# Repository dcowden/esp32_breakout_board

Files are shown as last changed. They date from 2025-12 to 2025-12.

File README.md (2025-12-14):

# esp32 breakout boards

These are for  this board:

https://docs.espressif.com/projects/esp-dev-kits/en/latest/esp32/_images/esp32_devkitC_v4_pinlayout.png

## Included boards
 1. **esp32_breakout_smt**  A board designed to expose the stuff i need for xcc tracker, all on one board, with smt style mounts
 2. **esp32_breakout_tht** Through hole version of the above ( again designed for the xc case in mind
 3. **esp32_breakout_tht2** A simple board designed to just break out pins-- and then extned through a shield approach
 4. **esp32_breakout_tht2_shield** A shield for the agove that adds the stuff needed for xc application
 
## The stuff that the XC board needs

The xc board logs data from an nrf52840 and sends it to an esp32 , which processes further. 
The board needs:
   1. esp32 devkit c ( we need all the pins) (38 pin)
   2. seed xiao nrf52840  (14 pin) 
   3. ds3231 (isc) (weird 5 pin thing)
   4. i2c oled 
   5. micro sd card holder ( spi )

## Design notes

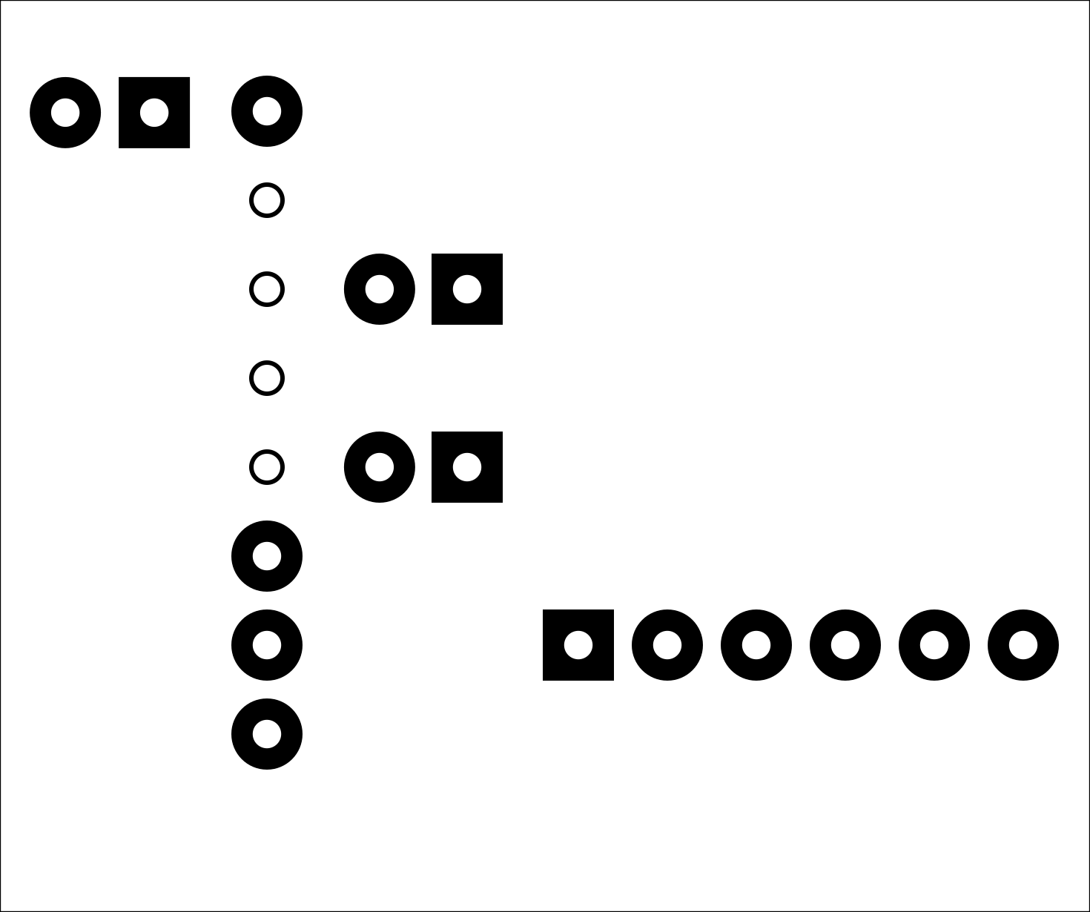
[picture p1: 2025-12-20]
sdcard_shield/board_art/mask-front.png

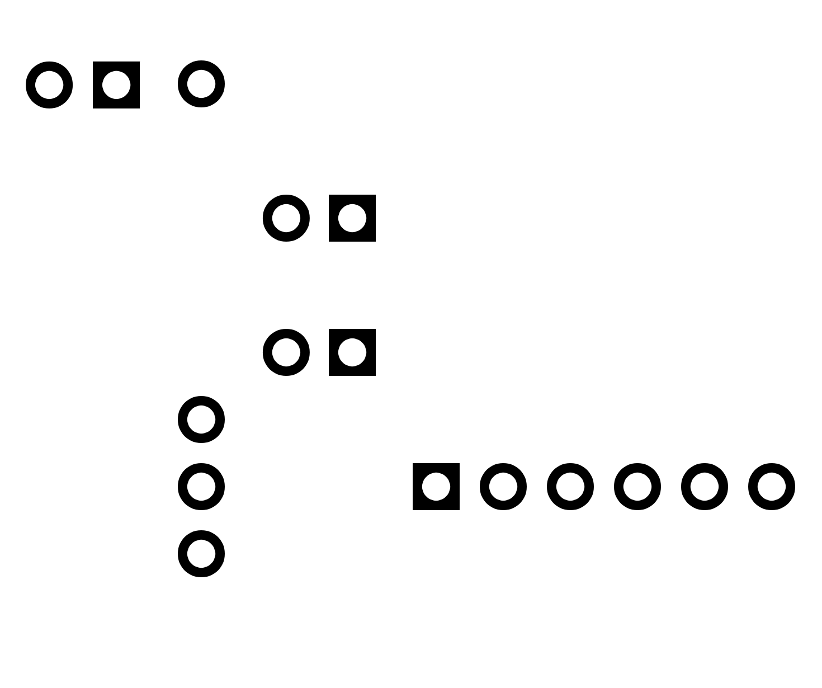
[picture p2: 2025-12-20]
sdcard_shield/board_art/mask-front_kerf.png

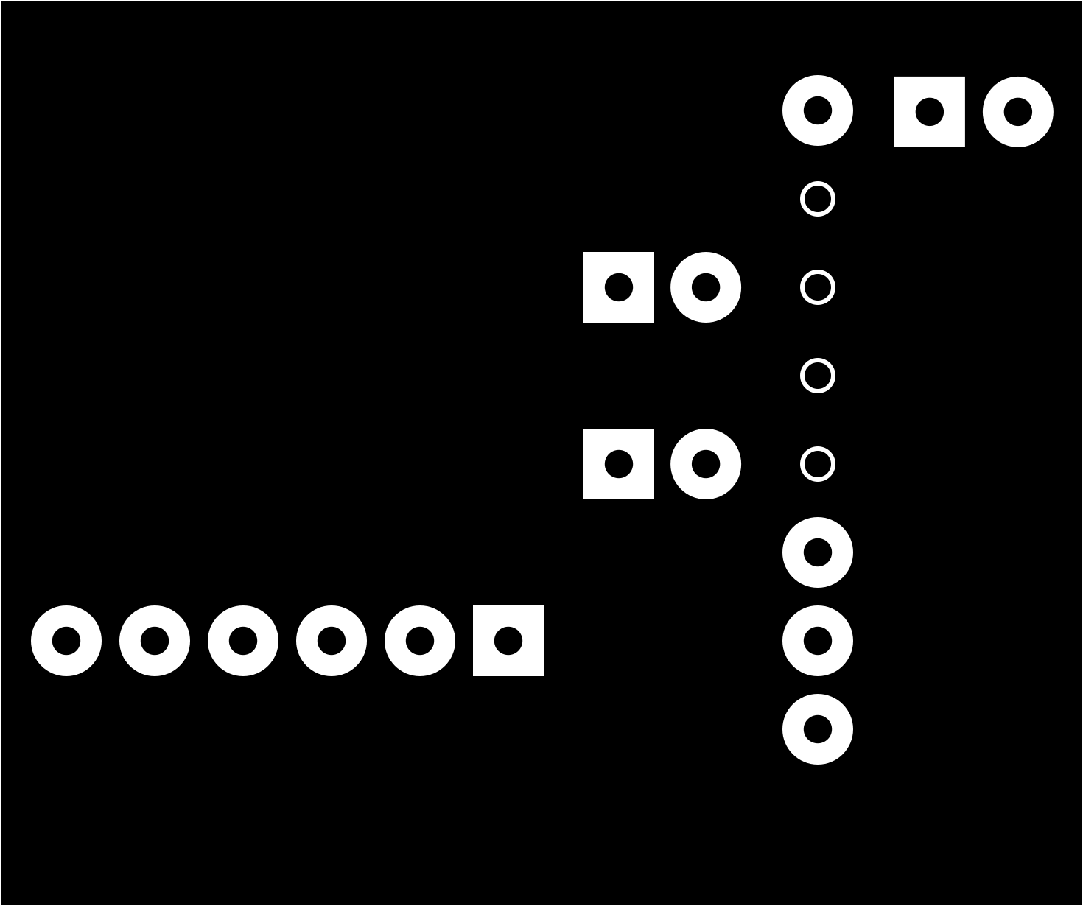
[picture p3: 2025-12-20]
sdcard_shield/board_art/back.png

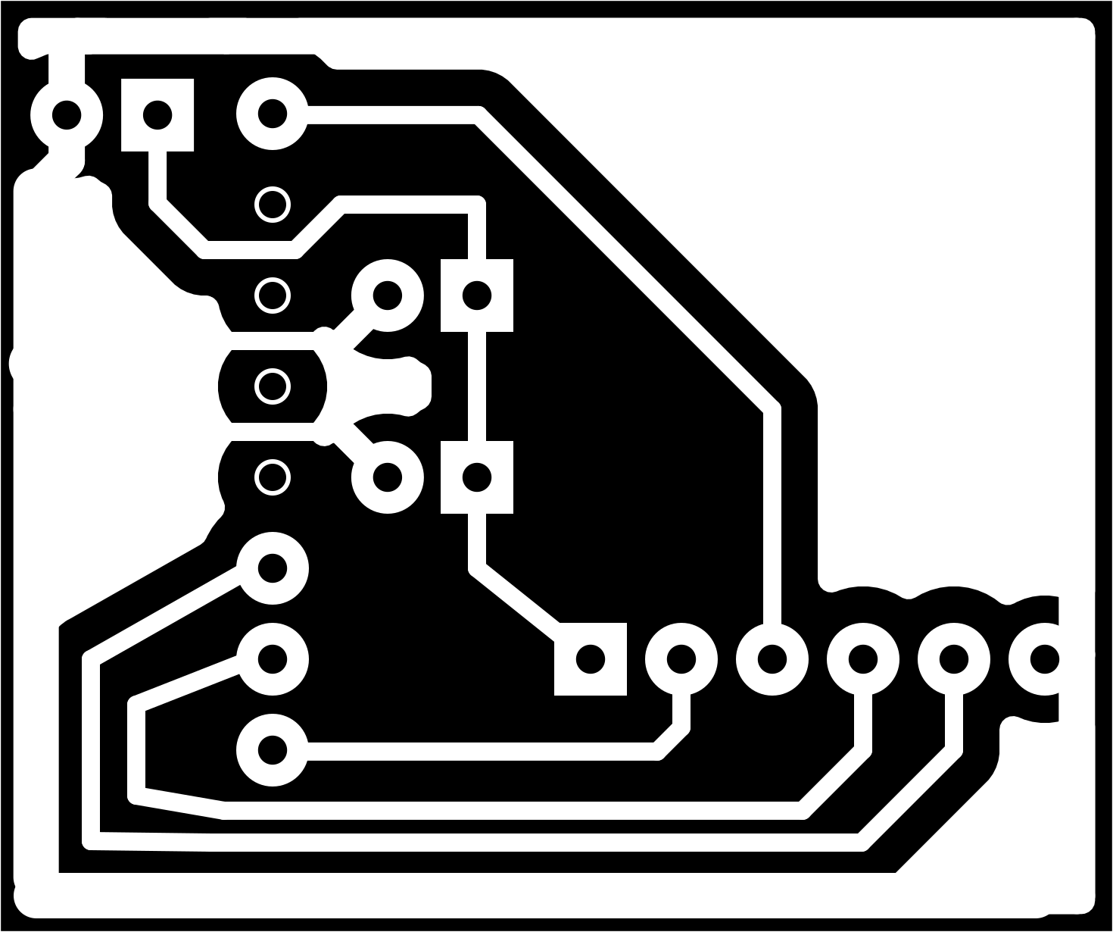
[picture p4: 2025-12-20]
sdcard_shield/board_art/front.png

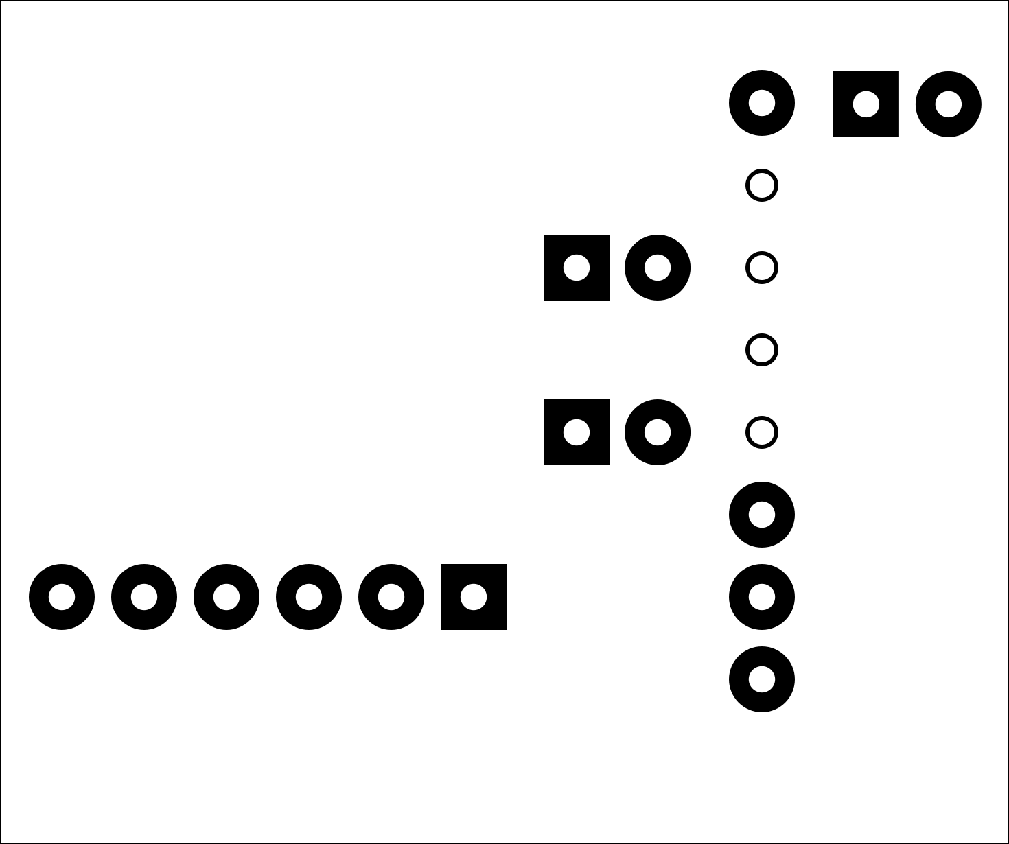
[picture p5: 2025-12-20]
sdcard_shield/board_art/mask-back.png

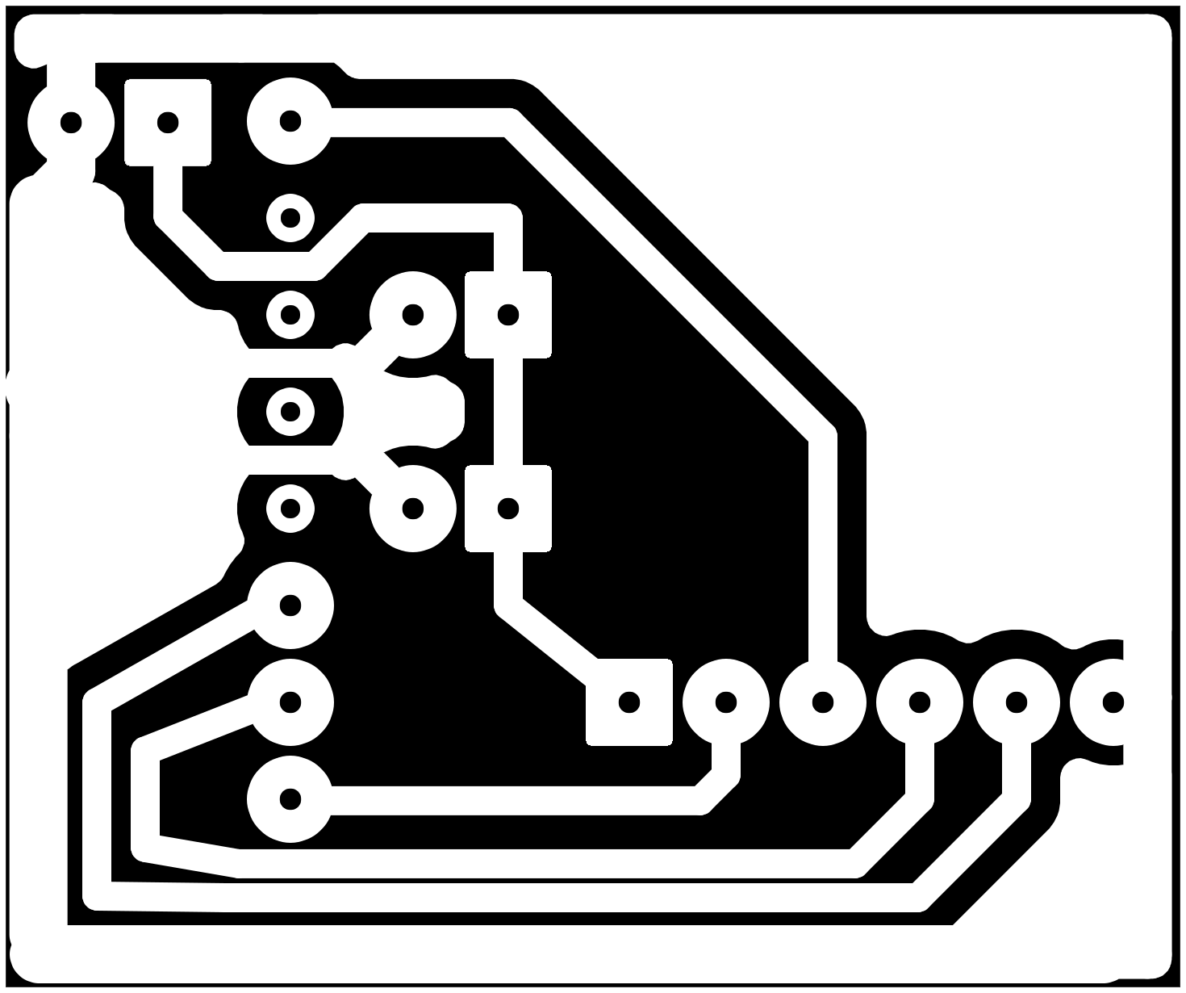
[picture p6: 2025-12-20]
sdcard_shield/board_art/front_kerf.png

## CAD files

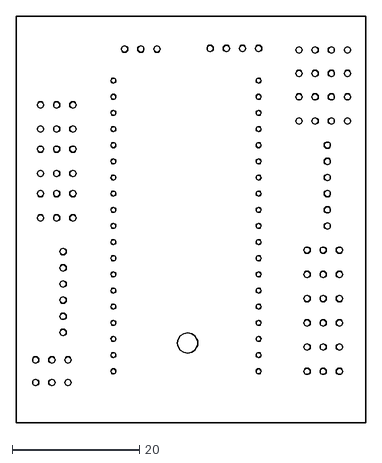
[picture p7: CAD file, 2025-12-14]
esp32_breakout_tht/board_art/back-silkscreen.dxf/esp32_breakout-Edge_Cuts.dxf
54.9 x 64.0

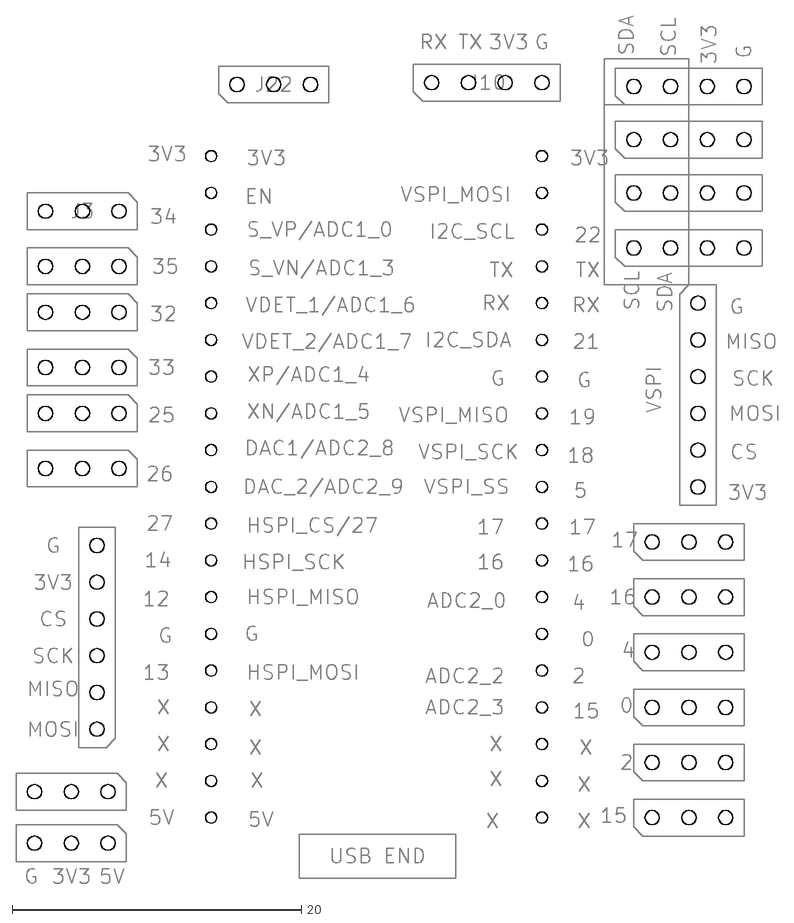
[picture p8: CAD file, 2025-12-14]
esp32_breakout_tht/board_art/front-silkscreen.dxf/esp32_breakout-F_Fab.dxf
52.6 x 59.9

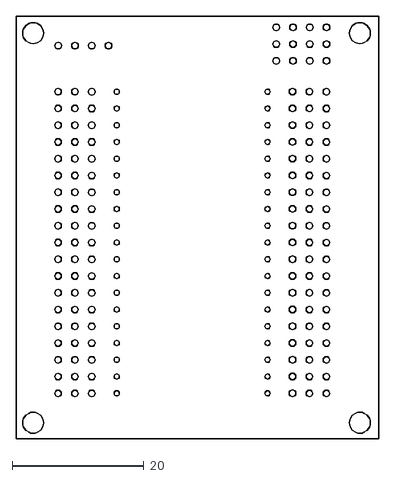
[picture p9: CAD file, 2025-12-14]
esp32_breakout_tht2/board_art/back-silkscreen.dxf/esp32_breakout-Edge_Cuts.dxf
54.9 x 64.0

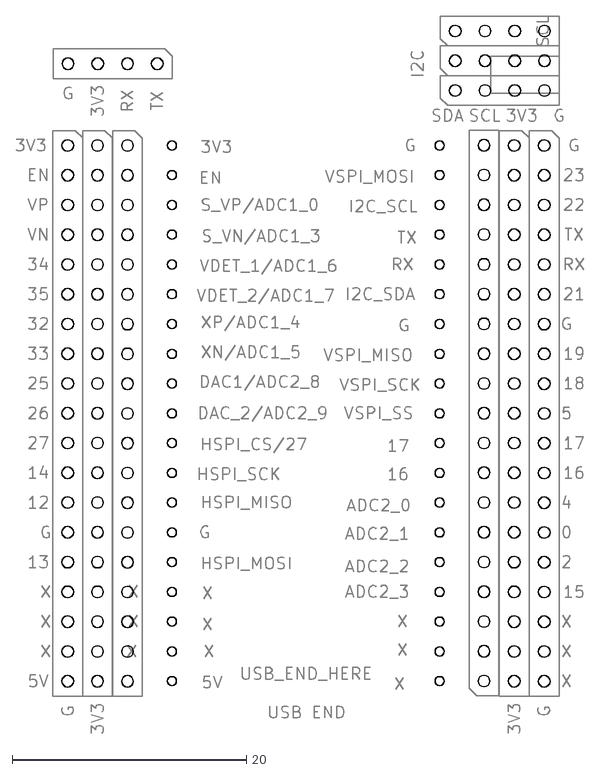
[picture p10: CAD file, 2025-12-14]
esp32_breakout_tht2/board_art/front-silkscreen.dxf/esp32_breakout-F_Fab.dxf
48.4 x 61.2

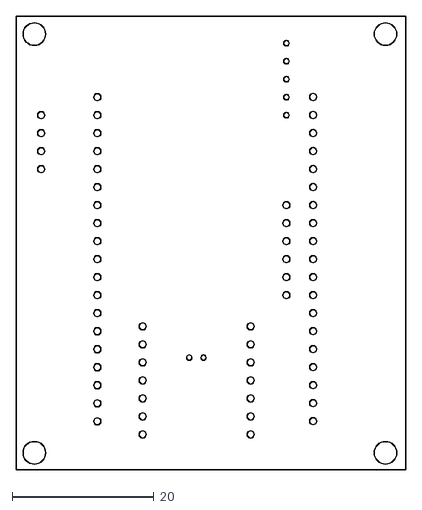
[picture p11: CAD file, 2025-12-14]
esp32_breakout_tht2_shield/board_art/back-silkscreen.dxf/esp32_breakout_shield-Edge_Cuts.dxf
54.9 x 64.0

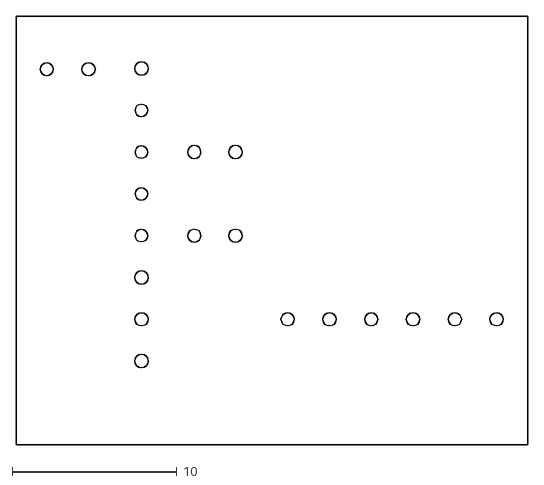
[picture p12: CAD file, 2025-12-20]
sdcard_shield/board_art/back-silkscreen.dxf/sdcard_shield-Edge_Cuts.dxf
31.1 x 26.0

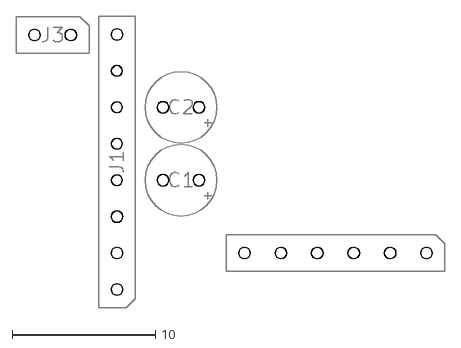
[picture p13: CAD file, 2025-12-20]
sdcard_shield/board_art/front-silkscreen.dxf/sdcard_shield-F_Fab.dxf
29.9 x 20.3

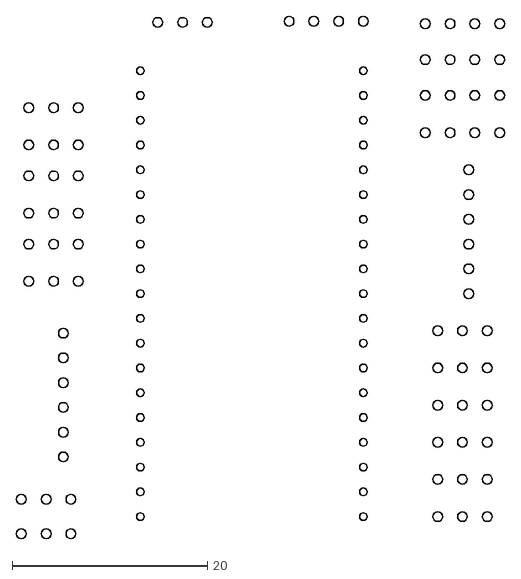
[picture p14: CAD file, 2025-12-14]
esp32_breakout_tht/board_art/cuts.dxf/esp32_breakout-User_Drawings.dxf
50.0 x 53.6

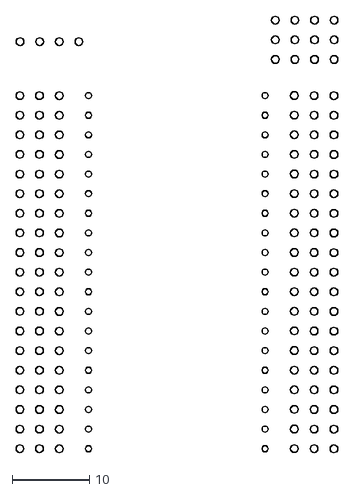
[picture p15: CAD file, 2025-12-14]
esp32_breakout_tht2/board_art/cuts.dxf/esp32_breakout-User_Drawings.dxf
41.7 x 56.5

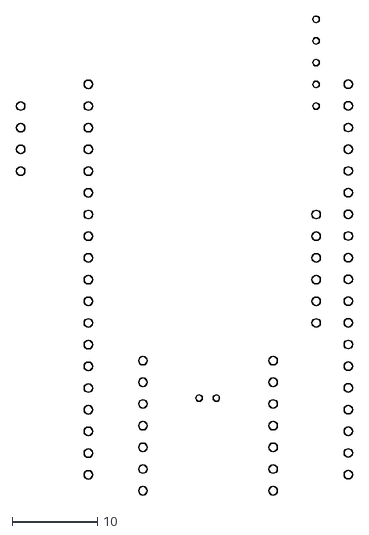
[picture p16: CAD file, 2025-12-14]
esp32_breakout_tht2_shield/board_art/cuts.dxf/esp32_breakout_shield-User_Drawings.dxf
39.4 x 56.1

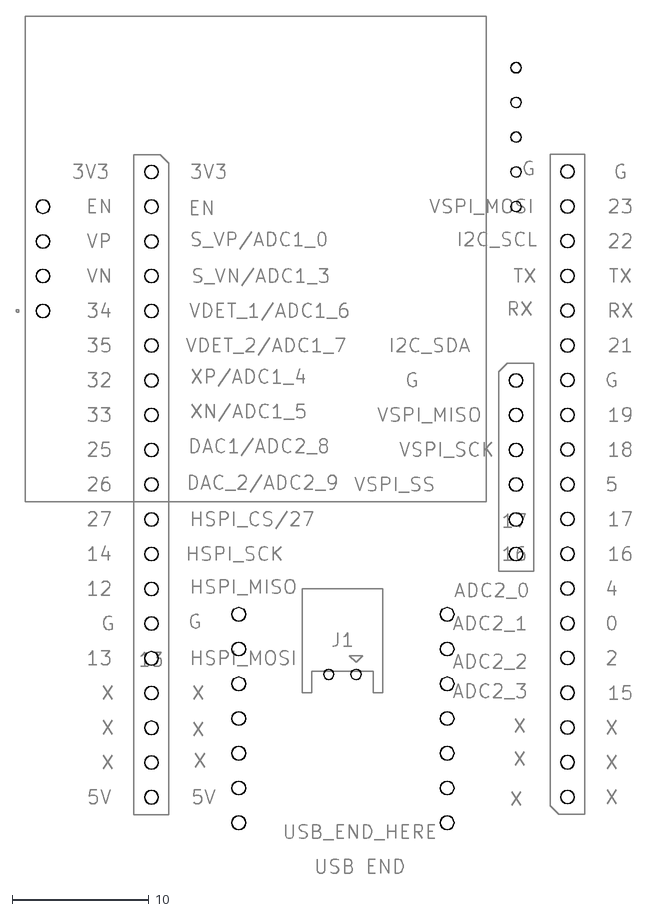
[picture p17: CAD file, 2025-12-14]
esp32_breakout_tht2_shield/board_art/front-silkscreen.dxf/esp32_breakout_shield-F_Fab.dxf
45.0 x 62.7

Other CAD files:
esp32_breakout_smt/board_art/back-silkscreen.dxf/esp32_breakout-B_Silkscreen.dxf
esp32_breakout_smt/board_art/back-silkscreen.dxf/esp32_breakout-Edge_Cuts.dxf
esp32_breakout_smt/board_art/cuts.dxf/esp32_breakout-Edge_Cuts.dxf
esp32_breakout_smt/board_art/cuts.dxf/esp32_breakout-User_Drawings.dxf
esp32_breakout_smt/board_art/front-silkscreen.dxf/esp32_breakout-Edge_Cuts.dxf
esp32_breakout_smt/board_art/front-silkscreen.dxf/esp32_breakout-F_Silkscreen.dxf
esp32_breakout_tht/board_art/front-silkscreen.dxf/esp32_breakout-F_Silkscreen.dxf
esp32_breakout_tht2/board_art/front-silkscreen.dxf/esp32_breakout-F_Silkscreen.dxf
esp32_breakout_tht2_shield/board_art/back-silkscreen.dxf/esp32_breakout_shield-B_Silkscreen.dxf
esp32_breakout_tht2_shield/board_art/front-silkscreen.dxf/esp32_breakout_shield-F_Silkscreen.dxf
sdcard_shield/board_art/back-silkscreen.dxf/sdcard_shield-B_Silkscreen.dxf
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

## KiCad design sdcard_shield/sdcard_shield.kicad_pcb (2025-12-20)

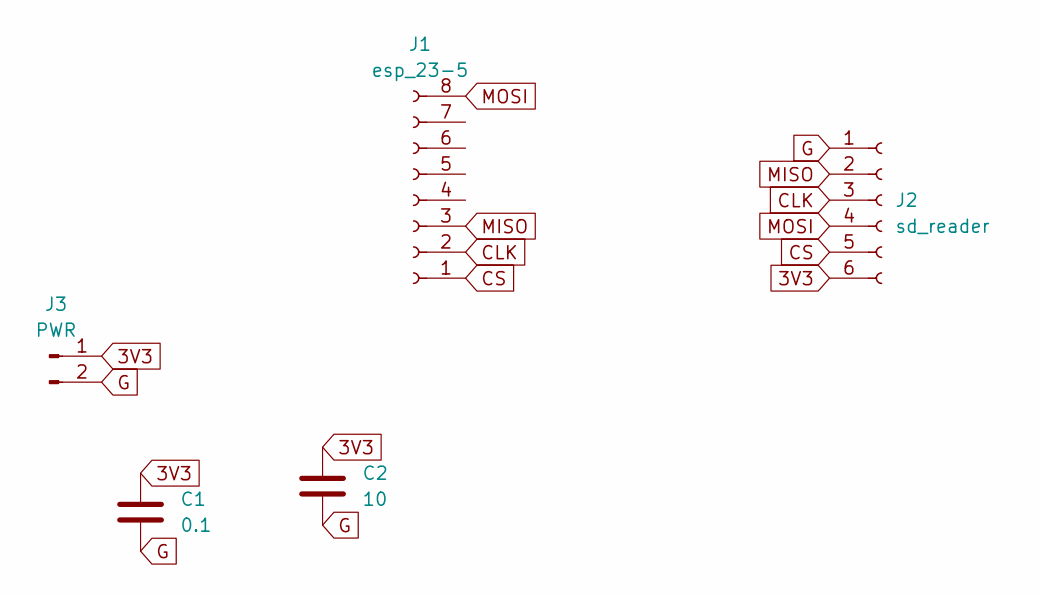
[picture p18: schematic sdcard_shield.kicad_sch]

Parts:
C1: 0.1; CP_Radial_D5.0mm_P2.50mm
C2: 10; CP_Radial_D5.0mm_P2.50mm
J1: esp_23-5; PinHeader_1x08_P2.54mm_Vertical
J2: sd_reader; PinHeader_1x06_P2.54mm_Vertical
J3: PWR; PinHeader_1x02_P2.54mm_Vertical

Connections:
3V3: C1.1, C2.1, J2.6, J3.1
CLK: J1.2, J2.3
CS: J1.1, J2.5
G: C1.2, C2.2, J2.1, J3.2
MISO: J1.3, J2.2
MOSI: J1.8, J2.4

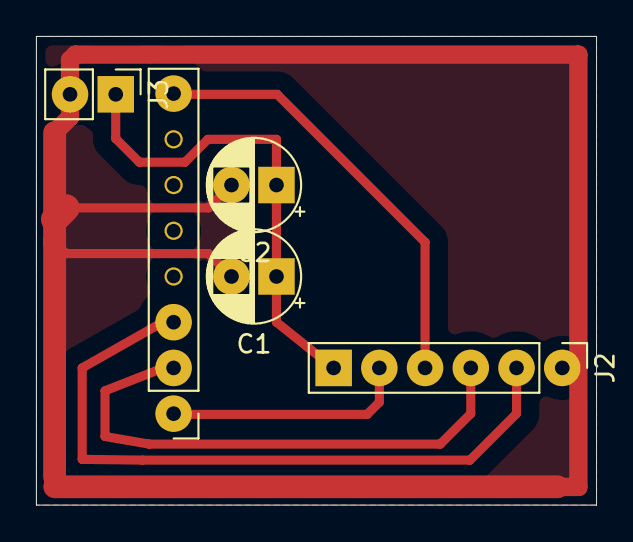
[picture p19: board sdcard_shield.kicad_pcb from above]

Board: 2 copper layers, 31.1 x 26.0 mm, 5 parts (0 on the bottom side), 6 nets.

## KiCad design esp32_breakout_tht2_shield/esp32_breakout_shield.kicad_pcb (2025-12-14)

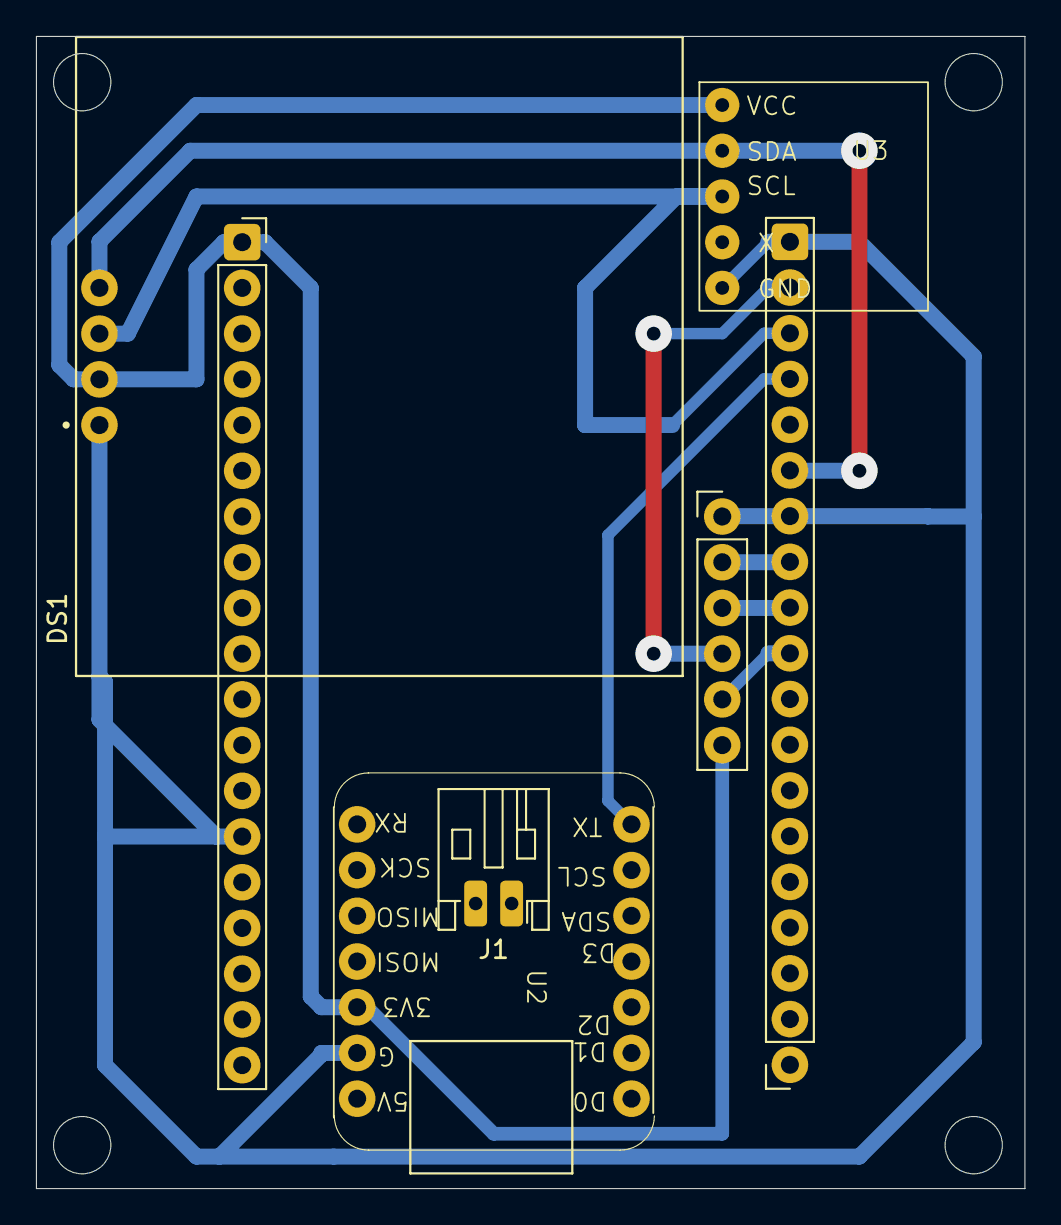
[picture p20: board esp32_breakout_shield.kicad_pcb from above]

Board: 2 copper layers, 54.9 x 64.0 mm, 7 parts (0 on the bottom side), 12 nets.

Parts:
DS1: OLED_128X64_1.3_I2C; LCD_OLED_128X64_1.3_I2C
J1: BAT; JST_PH_S2B-PH-K_1x02_P2.00mm_Horizontal
J21: SPI1; PinHeader_1x06_P2.54mm_Vertical
J23: s2; PinSocket_1x19_P2.54mm_Vertical_Tight
J24: s1; PinSocket_1x19_P2.54mm_Vertical_Tight
U2: XIAO_NRF52840
U3: DS3231

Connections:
3V3: DS1.2 (VDD), J21.6, J23.1, U2.5 (3V3), U3.1 (VCC)
GND: DS1.1 (GND), J21.1, J23.14, J24.13, J24.19, U2.6 (GND), U3.5 (GND)
I2C_SCL: DS1.3 (SCK), J24.17, U3.3 (SCL)
I2C_SDA: DS1.4 (SDA), J24.14, U3.2 (SDA)
unnamed: J1.1, U2.16 (BAT-)
unnamed: J1.2, U2.15 (BAT+)
SPI_CS: J21.5, J24.10
SPI_MISO: J21.2, J24.12
SPI_MOSI: J21.4, J24.18
SPI_SCK: J21.3, J24.11
U0_RX: J24.16, U2.8 (TX)
U0_TX: J24.15, U2.1 (RX)

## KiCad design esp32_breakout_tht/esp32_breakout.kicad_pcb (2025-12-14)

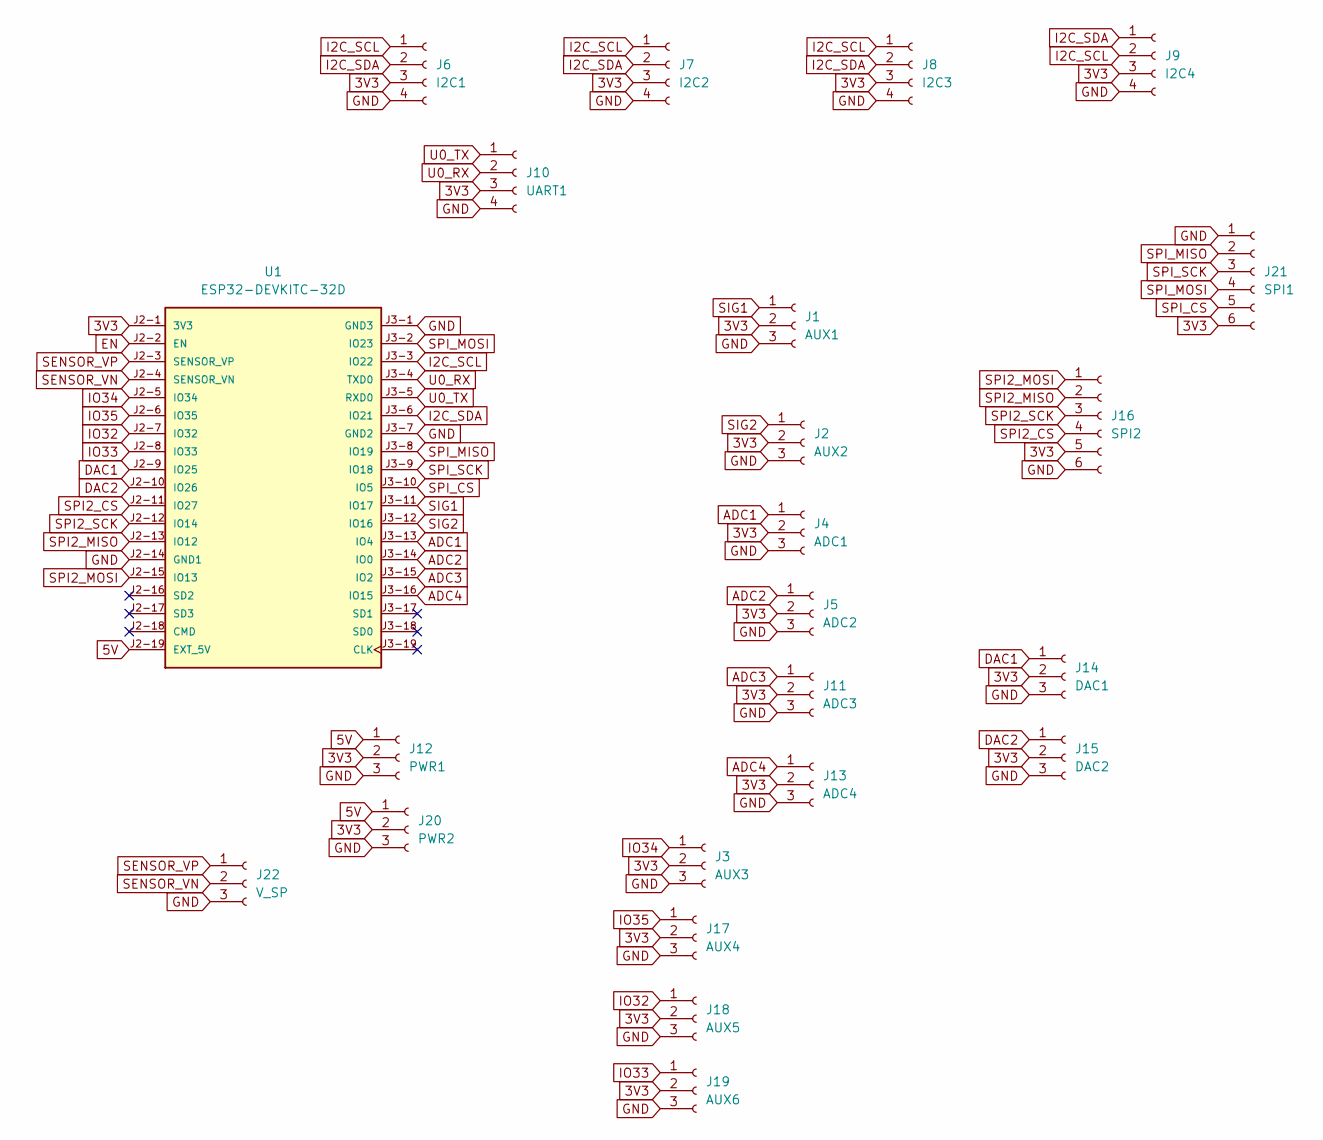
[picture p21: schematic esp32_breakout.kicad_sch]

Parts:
J1: AUX1; PinHeader_1x03_P2.54mm_Vertical
J2: AUX2; PinHeader_1x03_P2.54mm_Vertical
J3: AUX3; PinHeader_1x03_P2.54mm_Vertical
J4: ADC1; PinHeader_1x03_P2.54mm_Vertical
J5: ADC2; PinHeader_1x03_P2.54mm_Vertical
J6: I2C1; PinHeader_1x04_P2.54mm_Vertical
J7: I2C2; PinHeader_1x04_P2.54mm_Vertical
J8: I2C3; PinHeader_1x04_P2.54mm_Vertical
J9: I2C4; PinHeader_1x04_P2.54mm_Vertical
J10: UART1; PinHeader_1x04_P2.54mm_Vertical
J11: ADC3; PinHeader_1x03_P2.54mm_Vertical
J12: PWR1; PinHeader_1x03_P2.54mm_Vertical
J13: ADC4; PinHeader_1x03_P2.54mm_Vertical
J14: DAC1; PinHeader_1x03_P2.54mm_Vertical
J15: DAC2; PinHeader_1x03_P2.54mm_Vertical
J16: SPI2; PinHeader_1x06_P2.54mm_Vertical
J17: AUX4; PinHeader_1x03_P2.54mm_Vertical
J18: AUX5; PinHeader_1x03_P2.54mm_Vertical
J19: AUX6; PinHeader_1x03_P2.54mm_Vertical
J20: PWR2; PinHeader_1x03_P2.54mm_Vertical
J21: SPI1; PinHeader_1x06_P2.54mm_Vertical
J22: V_SP; PinHeader_1x03_P2.54mm_Vertical
U1: ESP32-DEVKITC-32D; MODULE_ESP32-DEVKITC-32D-THT; PARTREV V4

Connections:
3V3: J1.2, J2.2, J3.2, J4.2, J5.2, J6.3, J7.3, J8.3, J9.3, J10.3, J11.2, J12.2, J13.2, J14.2, J15.2, J16.5, J17.2, J18.2, J19.2, J20.2, J21.6, U1.J2-1 (3V3)
5V: J12.1, J20.1, U1.J2-19 (EXT_5V)
ADC1: J4.1, U1.J3-13 (IO4)
ADC2: J5.1, U1.J3-14 (IO0)
ADC3: J11.1, U1.J3-15 (IO2)
ADC4: J13.1, U1.J3-16 (IO15)
DAC1: J14.1, U1.J2-9 (IO25)
DAC2: J15.1, U1.J2-10 (IO26)
EN: U1.J2-2 (EN)
GND: J1.3, J2.3, J3.3, J4.3, J5.3, J6.4, J7.4, J8.4, J9.4, J10.4, J11.3, J12.3, J13.3, J14.3, J15.3, J16.6, J17.3, J18.3, J19.3, J20.3, J21.1, J22.3, U1.J2-14 (GND1), U1.J3-1 (GND3), U1.J3-7 (GND2)
I2C_SCL: J6.1, J7.1, J8.1, J9.2, U1.J3-3 (IO22)
I2C_SDA: J6.2, J7.2, J8.2, J9.1, U1.J3-6 (IO21)
IO32: J18.1, U1.J2-7 (IO32)
IO33: J19.1, U1.J2-8 (IO33)
IO34: J3.1, U1.J2-5 (IO34)
IO35: J17.1, U1.J2-6 (IO35)
SENSOR_VN: J22.2, U1.J2-4 (SENSOR_VN)
SENSOR_VP: J22.1, U1.J2-3 (SENSOR_VP)
SIG1: J1.1, U1.J3-11 (IO17)
SIG2: J2.1, U1.J3-12 (IO16)
SPI2_CS: J16.4, U1.J2-11 (IO27)
SPI2_MISO: J16.2, U1.J2-13 (IO12)
SPI2_MOSI: J16.1, U1.J2-15 (IO13)
SPI2_SCK: J16.3, U1.J2-12 (IO14)
SPI_CS: J21.5, U1.J3-10 (IO5)
SPI_MISO: J21.2, U1.J3-8 (IO19)
SPI_MOSI: J21.4, U1.J3-2 (IO23)
SPI_SCK: J21.3, U1.J3-9 (IO18)
U0_RX: J10.2, U1.J3-4 (TXD0)
U0_TX: J10.1, U1.J3-5 (RXD0)

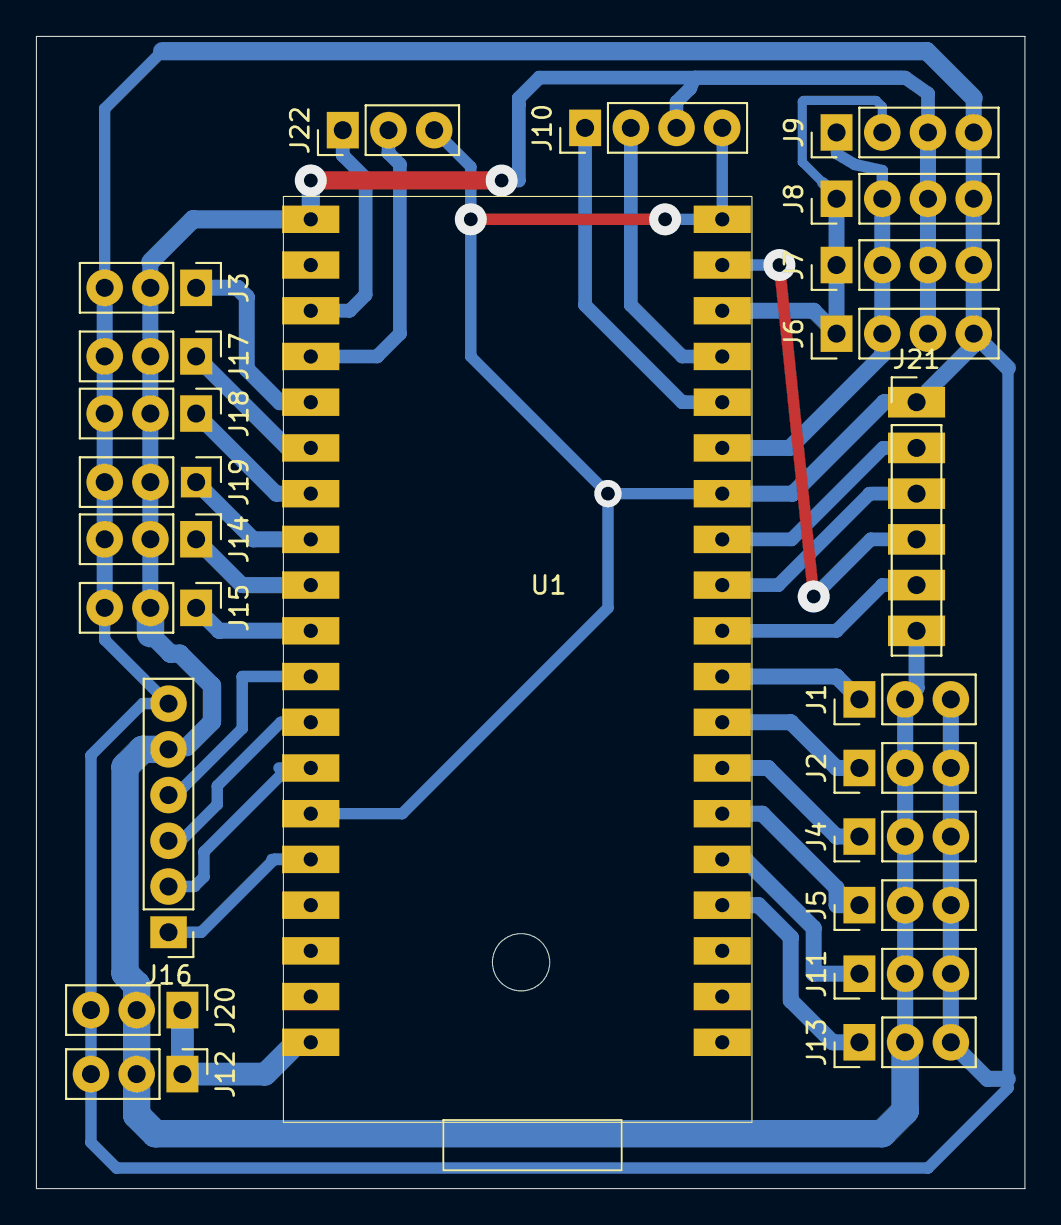
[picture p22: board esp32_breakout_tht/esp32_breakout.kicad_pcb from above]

Board: 2 copper layers, 54.9 x 64.0 mm, 23 parts (0 on the bottom side), 29 nets.

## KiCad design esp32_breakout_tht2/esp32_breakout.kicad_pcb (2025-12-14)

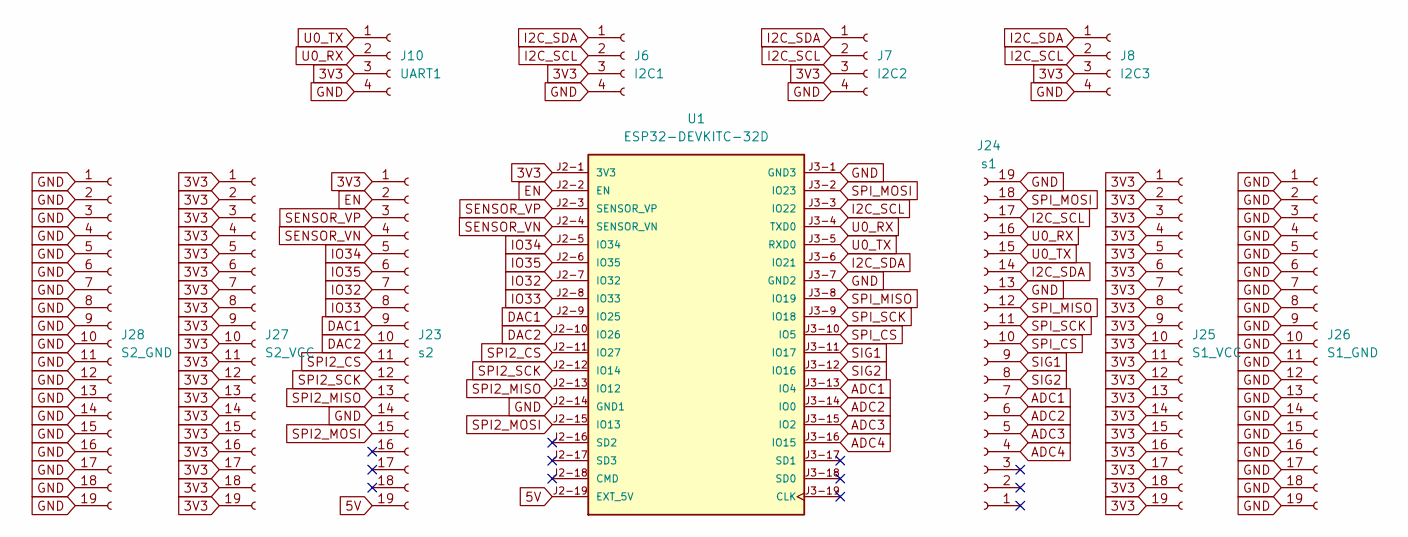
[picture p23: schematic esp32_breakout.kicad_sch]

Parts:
J6: I2C1; PinHeader_1x04_P2.54mm_Vertical_tight
J7: I2C2; PinHeader_1x04_P2.54mm_Vertical_tight
J8: I2C3; PinHeader_1x04_P2.54mm_Vertical_tight
J10: UART1; PinHeader_1x04_P2.54mm_Vertical_tight
J23: s2; PinSocket_1x19_P2.54mm_Vertical_Tight
J24: s1; PinSocket_1x19_P2.54mm_Vertical_Tight
J25: S1_VCC; PinSocket_1x19_P2.54mm_Vertical_Tight
J26: S1_GND; PinSocket_1x19_P2.54mm_Vertical_Tight
J27: S2_VCC; PinSocket_1x19_P2.54mm_Vertical_Tight
J28: S2_GND; PinSocket_1x19_P2.54mm_Vertical_Tight
U1: ESP32-DEVKITC-32D; MODULE_ESP32-DEVKITC-32D-THT; PARTREV V4

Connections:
3V3: J6.3, J7.3, J8.3, J10.3, J23.1, J25.1, J25.2, J25.3, J25.4, J25.5, J25.6, J25.7, J25.8, J25.9, J25.10, J25.11, J25.12, J25.13, J25.14, J25.15, J25.16, J25.17, J25.18, J25.19, J27.1, J27.2, J27.3, J27.4, J27.5, J27.6, J27.7, J27.8, J27.9, J27.10, J27.11, J27.12, J27.13, J27.14, J27.15, J27.16, J27.17, J27.18, J27.19, U1.J2-1 (3V3)
5V: J23.19, U1.J2-19 (EXT_5V)
ADC1: J24.7, U1.J3-13 (IO4)
ADC2: J24.6, U1.J3-14 (IO0)
ADC3: J24.5, U1.J3-15 (IO2)
ADC4: J24.4, U1.J3-16 (IO15)
DAC1: J23.9, U1.J2-9 (IO25)
DAC2: J23.10, U1.J2-10 (IO26)
EN: J23.2, U1.J2-2 (EN)
GND: J6.4, J7.4, J8.4, J10.4, J23.14, J24.13, J24.19, J26.1, J26.2, J26.3, J26.4, J26.5, J26.6, J26.7, J26.8, J26.9, J26.10, J26.11, J26.12, J26.13, J26.14, J26.15, J26.16, J26.17, J26.18, J26.19, J28.1, J28.2, J28.3, J28.4, J28.5, J28.6, J28.7, J28.8, J28.9, J28.10, J28.11, J28.12, J28.13, J28.14, J28.15, J28.16, J28.17, J28.18, J28.19, U1.J2-14 (GND1), U1.J3-1 (GND3), U1.J3-7 (GND2)
I2C_SCL: J6.2, J7.2, J8.2, J24.17, U1.J3-3 (IO22)
I2C_SDA: J6.1, J7.1, J8.1, J24.14, U1.J3-6 (IO21)
IO32: J23.7, U1.J2-7 (IO32)
IO33: J23.8, U1.J2-8 (IO33)
IO34: J23.5, U1.J2-5 (IO34)
IO35: J23.6, U1.J2-6 (IO35)
SENSOR_VN: J23.4, U1.J2-4 (SENSOR_VN)
SENSOR_VP: J23.3, U1.J2-3 (SENSOR_VP)
SIG1: J24.9, U1.J3-11 (IO17)
SIG2: J24.8, U1.J3-12 (IO16)
SPI2_CS: J23.11, U1.J2-11 (IO27)
SPI2_MISO: J23.13, U1.J2-13 (IO12)
SPI2_MOSI: J23.15, U1.J2-15 (IO13)
SPI2_SCK: J23.12, U1.J2-12 (IO14)
SPI_CS: J24.10, U1.J3-10 (IO5)
SPI_MISO: J24.12, U1.J3-8 (IO19)
SPI_MOSI: J24.18, U1.J3-2 (IO23)
SPI_SCK: J24.11, U1.J3-9 (IO18)
U0_RX: J10.2, J24.16, U1.J3-4 (TXD0)
U0_TX: J10.1, J24.15, U1.J3-5 (RXD0)

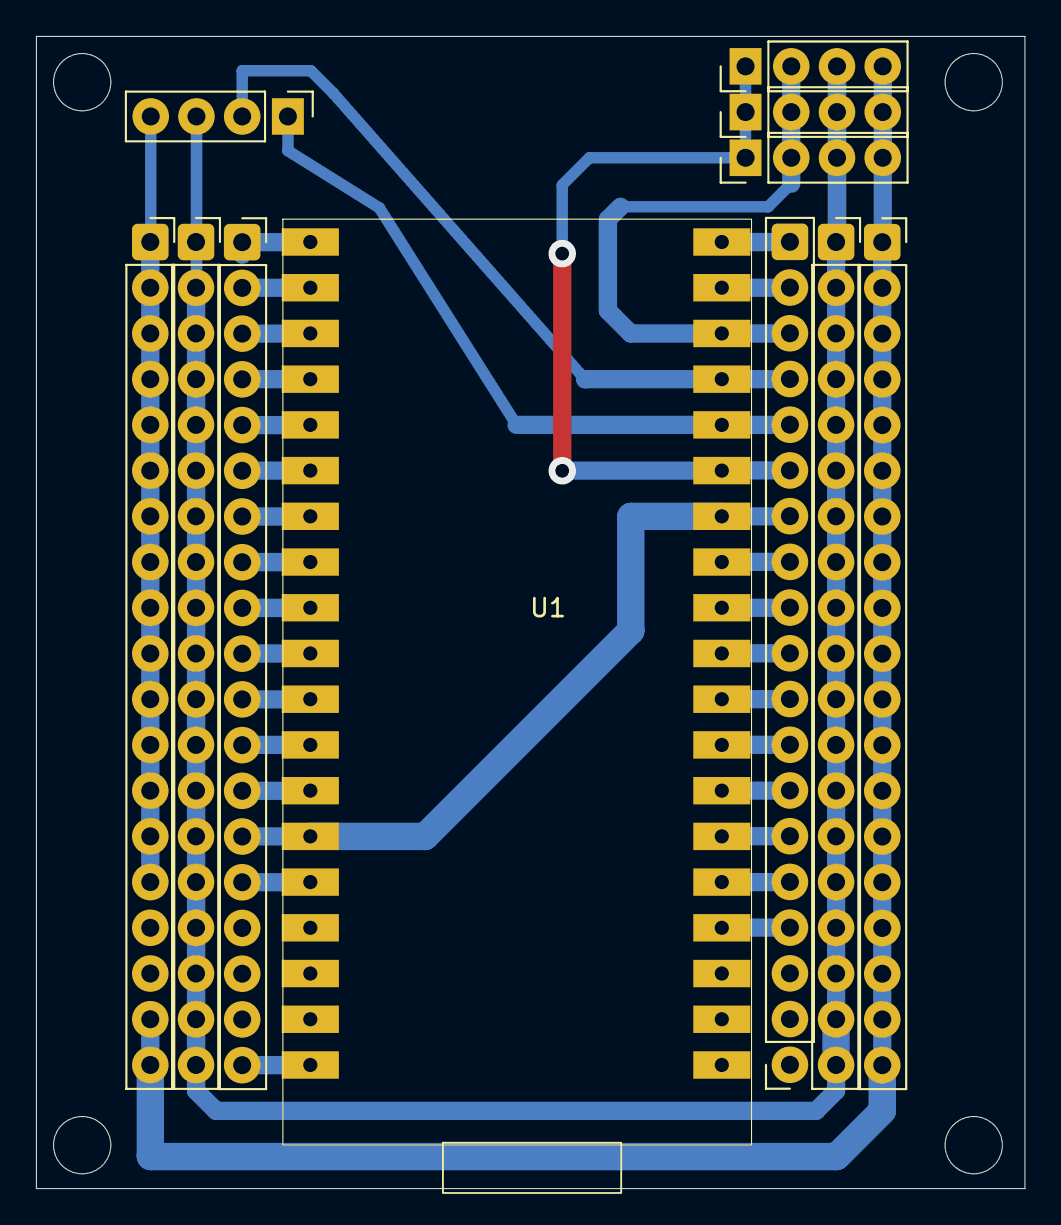
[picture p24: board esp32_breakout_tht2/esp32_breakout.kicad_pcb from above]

Board: 2 copper layers, 54.9 x 64.0 mm, 11 parts (0 on the bottom side), 30 nets.

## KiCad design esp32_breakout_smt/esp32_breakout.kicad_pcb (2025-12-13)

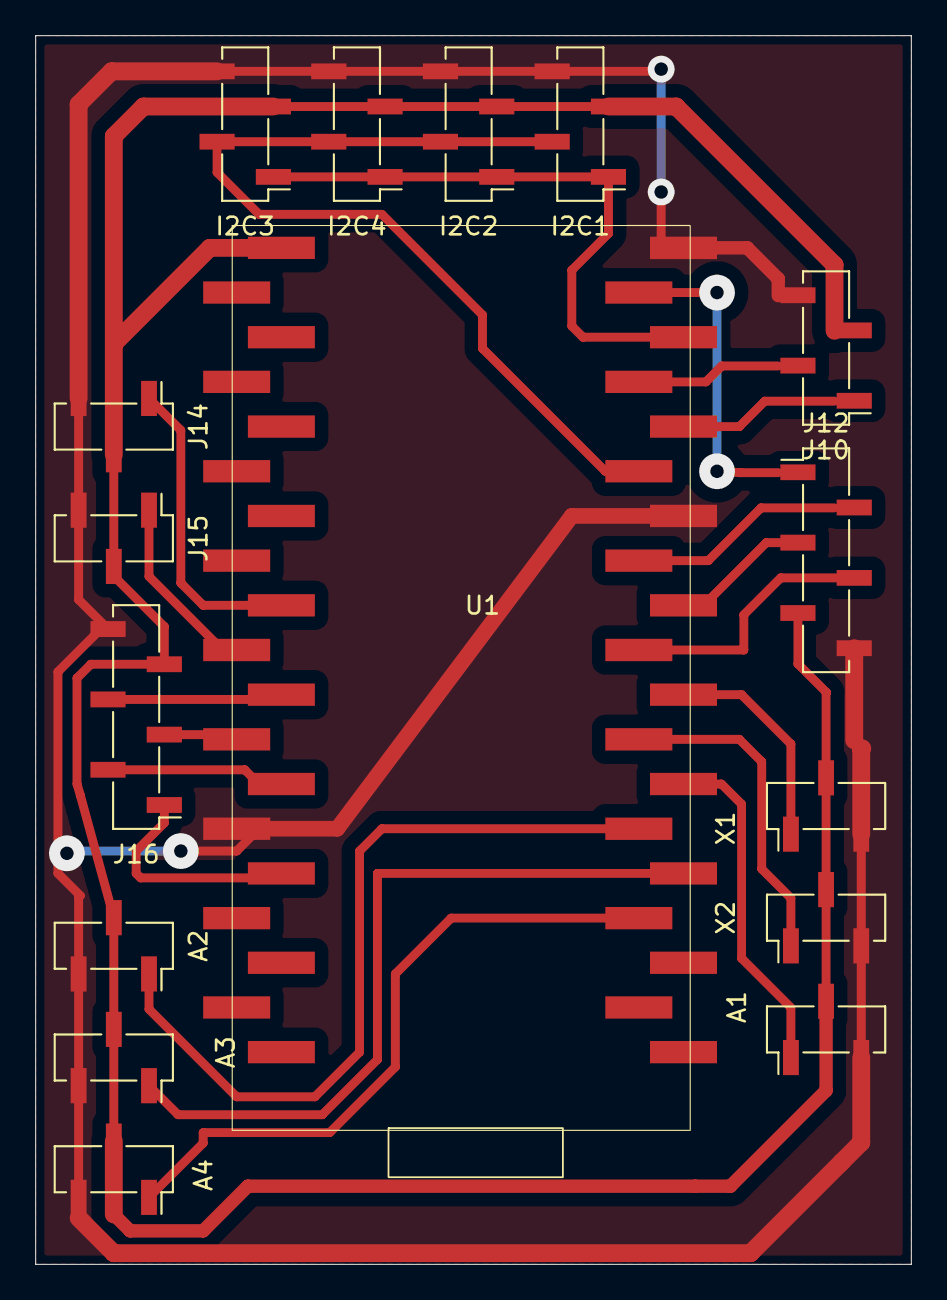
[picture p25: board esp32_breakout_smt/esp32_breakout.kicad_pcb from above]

Board: 2 copper layers, 49.8 x 69.8 mm, 16 parts (0 on the bottom side), 22 nets.

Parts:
A1: ADC1; PinSocket_1x03_P2.00mm_Vertical_SMD_Pin1Left
A2: ADC2; PinSocket_1x03_P2.00mm_Vertical_SMD_Pin1Right
A3: ADC3; PinSocket_1x03_P2.00mm_Vertical_SMD_Pin1Right
A4: ADC4; PinSocket_1x03_P2.00mm_Vertical_SMD_Pin1Right
I2C1: I2C1; PinSocket_1x04_P2.00mm_Vertical_SMD_Pin1Left
I2C2: I2C2; PinSocket_1x04_P2.00mm_Vertical_SMD_Pin1Left
I2C3: I2C4; PinSocket_1x04_P2.00mm_Vertical_SMD_Pin1Left
I2C4: I2C3; PinSocket_1x04_P2.00mm_Vertical_SMD_Pin1Left
J10: UART1; PinSocket_1x04_P2.00mm_Vertical_SMD_Pin1Left
J12: SPI1; PinSocket_1x06_P2.00mm_Vertical_SMD_Pin1Left
J14: DAC1; PinSocket_1x03_P2.00mm_Vertical_SMD_Pin1Left
J15: DAC2; PinSocket_1x03_P2.00mm_Vertical_SMD_Pin1Left
J16: SPI2; PinSocket_1x06_P2.00mm_Vertical_SMD_Pin1Left
U1: ESP32-DEVKITC-32D; MODULE_ESP32-DEVKITC-32D
X1: AUX1; PinSocket_1x03_P2.00mm_Vertical_SMD_Pin1Left
X2: AUX2; PinSocket_1x03_P2.00mm_Vertical_SMD_Pin1Left

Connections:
3V3: A1.2, A2.2, A3.2, A4.2, I2C1.3, I2C2.3, I2C3.3, I2C4.3, J10.3, J12.5, J14.2, J15.2, J16.5, U1.J2-1 (3V3), X1.2, X2.2
ADC1: A1.1, U1.J3-13 (IO4)
ADC2: A2.1, U1.J3-14 (IO0)
ADC3: A3.1, U1.J3-15 (IO2)
ADC4: A4.1, U1.J3-16 (IO15)
DAC1: J14.1, U1.J2-9 (IO25)
DAC2: J15.1, U1.J2-10 (IO26)
GND: A1.3, A2.3, A3.3, A4.3, I2C1.4, I2C2.4, I2C3.4, I2C4.4, J10.4, J12.6, J14.3, J15.3, J16.6, U1.J2-14 (GND1), U1.J3-1 (GND3), U1.J3-7 (GND2), X1.3, X2.3
I2C_SCL: I2C1.1, I2C2.1, I2C3.1, I2C4.1, U1.J3-3 (IO22)
I2C_SDA: I2C1.2, I2C2.2, I2C3.2, I2C4.2, U1.J3-6 (IO21)
SIG1: U1.J3-11 (IO17), X1.1
SIG2: U1.J3-12 (IO16), X2.1
SPI2_CS: J16.4, U1.J2-11 (IO27)
SPI2_MISO: J16.2, U1.J2-13 (IO12)
SPI2_MOSI: J16.1, U1.J2-15 (IO13)
SPI2_SCK: J16.3, U1.J2-12 (IO14)
SPI_CS: J12.4, U1.J3-10 (IO5)
SPI_MISO: J12.2, U1.J3-8 (IO19)
SPI_MOSI: J12.1, U1.J3-2 (IO23)
SPI_SCK: J12.3, U1.J3-9 (IO18)
U0_RX: J10.2, U1.J3-4 (TXD0)
U0_TX: J10.1, U1.J3-5 (RXD0)

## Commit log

2025-12-13 first version
    [esp32_breakout-B_Silkscreen.dxf, esp32_breakout-Edge_Cuts.dxf, esp32_breakout-F_Silkscreen.dxf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]
2025-12-13 little bigger board
    [esp32_breakout-Edge_Cuts.dxf, esp32_breakout-F_Silkscreen.dxf, esp32_breakout.kicad_pcb]
2025-12-13 handled kerf
    [esp32_breakout.kicad_pcb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]
2025-12-14 now the kerf adjust is actually working
    [esp32_breakout-Edge_Cuts.gbr, esp32_breakout-F_Cu.gbr, esp32_breakout-F_Mask.gbr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]
2025-12-14 made shield style boards
    [esp32_breakout-B_Silkscreen.dxf, esp32_breakout-Edge_Cuts.dxf, esp32_breakout-F_Silkscreen.dxf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]
2025-12-14 describe what all these boards are
2025-12-14 generated all the boards, touched up
    [esp32_breakout-B_Silkscreen.dxf, esp32_breakout-Edge_Cuts.dxf, esp32_breakout-F_Fab.dxf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]
2025-12-14 added fab alignment box
    [esp32_breakout.kicad_pcb, esp32_breakout_shield.kicad_pcb]
2025-12-20 added sdcard shield to clean up reliability
    [sdcard_shield-B_Silkscreen.dxf, sdcard_shield-Edge_Cuts.dxf, sdcard_shield-F_Fab.dxf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]
2025-12-20 fixed it
    [sdcard_shield-B_Silkscreen.dxf, sdcard_shield-Edge_Cuts.dxf, sdcard_shield-F_Fab.dxf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]
2025-12-20 dammit. fixed
    [sdcard_shield-B_Silkscreen.dxf, sdcard_shield-Edge_Cuts.dxf, sdcard_shield-F_Fab.dxf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]
